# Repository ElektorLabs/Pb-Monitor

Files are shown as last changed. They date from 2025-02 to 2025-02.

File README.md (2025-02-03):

# Pb-Monitor

Pb-Monitor is a project developed by ElektorLabs aimed at monitoring lead-acid batteries. This repository contains both hardware schematics and firmware source code to facilitate the monitoring process.

## Features

- **Hardware Design**: Detailed schematics and design files for building the Pb-Monitor hardware.
- **Firmware**: Source code for the microcontroller to interface with the hardware and perform monitoring tasks.

## Repository Structure

- **hardware/**: Contains all hardware design files and schematics.
- **src/PbMonitor/**: Contains the firmware source code for the Pb-Monitor.

## Getting Started

To get started with Pb-Monitor:

1. **Clone the Repository**:
   ```bash
   git clone https://github.com/ElektorLabs/Pb-Monitor.git
   ```
2. **Explore the Hardware Design**:
   - Navigate to the `hardware/` directory to find schematics and design files.
3. **Build the Firmware**:
   - Navigate to the `src/PbMonitor/` directory.
   - Follow the build instructions provided in the source code to compile and upload the firmware to your microcontroller.

## License

This project is licensed under the GNU General Public License v3.0. For more details, refer to the [LICENSE](https://github.com/ElektorLabs/Pb-Monitor/blob/main/LICENSE) file.

## Contributing

Contributions are welcome! If you have suggestions or improvements, feel free to open an issue or submit a pull request.

## Contact

For more information or support, please contact ElektorLabs through their [GitHub profile](https://github.com/ElektorLabs).

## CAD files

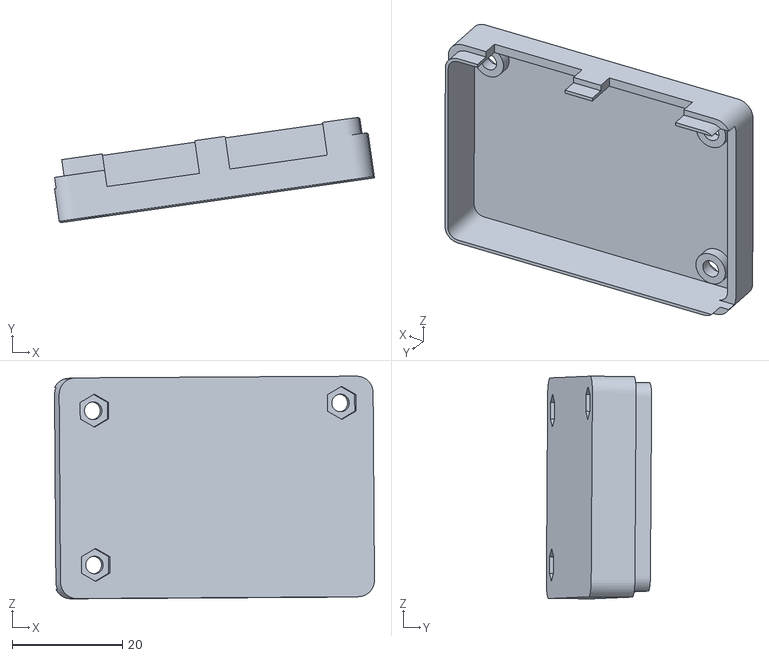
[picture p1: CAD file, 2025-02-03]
hardware/cad/stl/Pb_Enclosure - Pb Enclosure_Button-1.STL
58.0 x 19.1 x 40.4

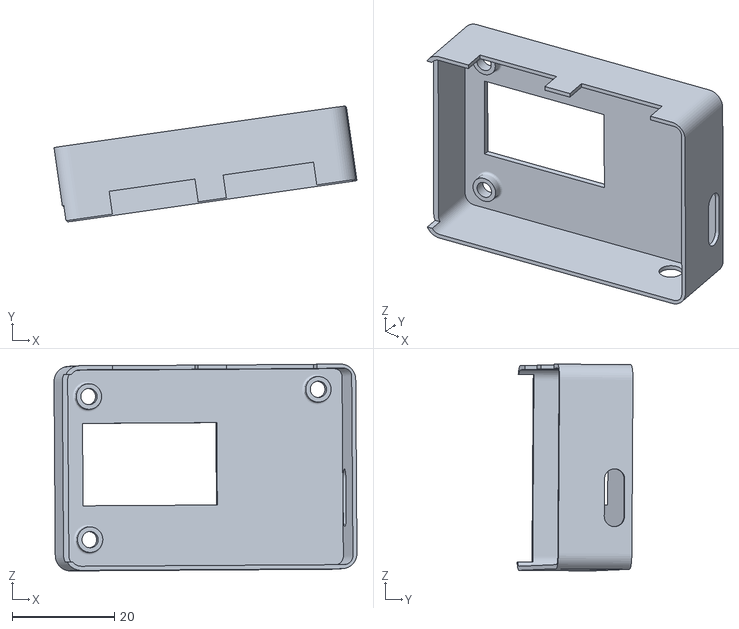
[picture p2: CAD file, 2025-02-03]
hardware/cad/stl/Pb_Enclosure - Pb Enclosure_Top-1.STL
59.2 x 22.7 x 40.4

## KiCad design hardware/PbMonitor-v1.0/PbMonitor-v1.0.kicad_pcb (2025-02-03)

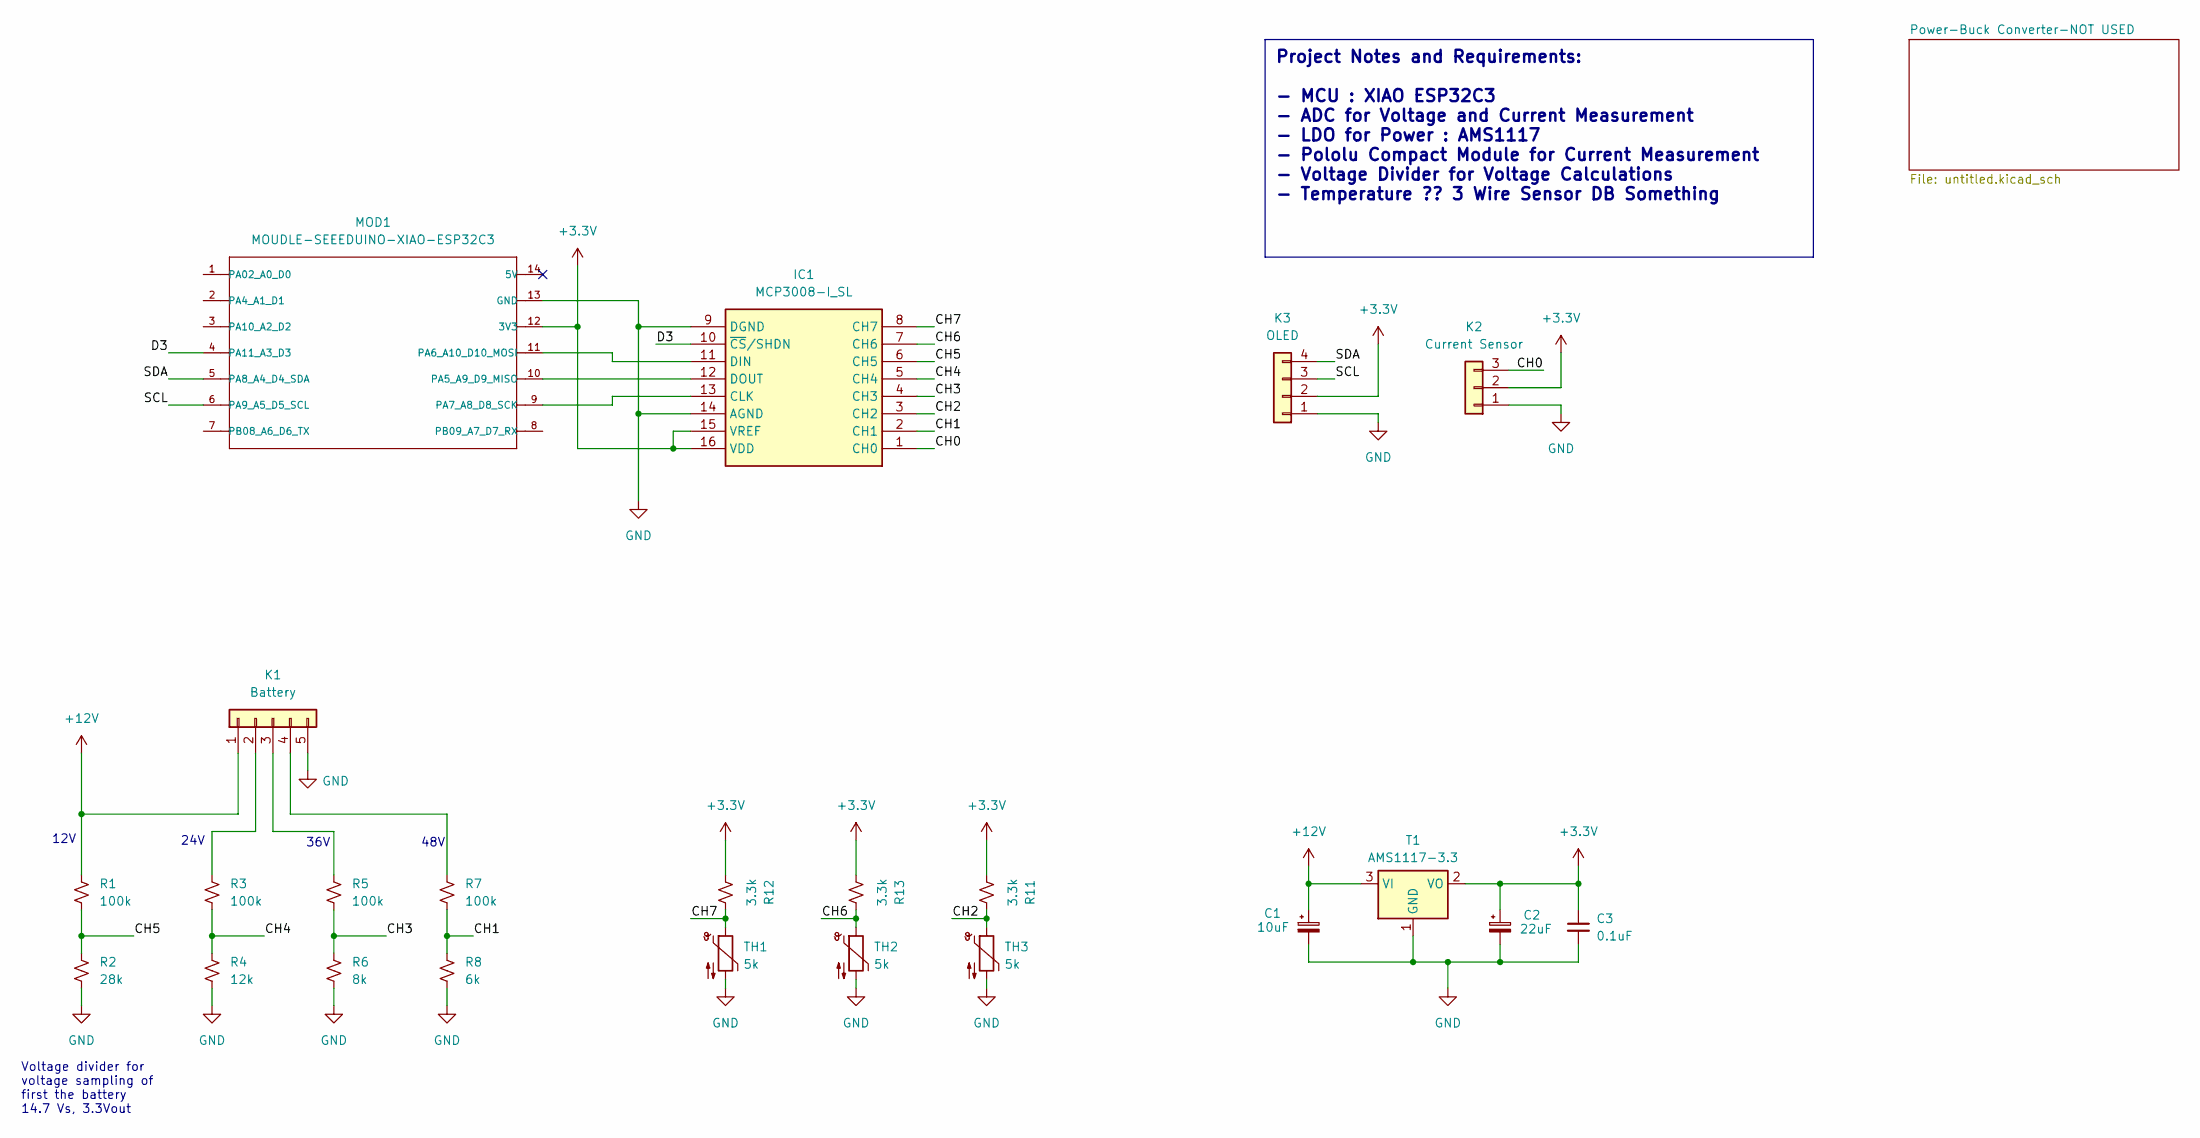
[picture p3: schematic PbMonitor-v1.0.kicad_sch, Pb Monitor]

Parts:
C1: 10uF; CP_Radial_D4.0mm_P1.50mm
C2: 22uF; CP_Radial_D4.0mm_P1.50mm
C3: 0.1uF; C_0805_2012Metric_Pad1.18x1.45mm_HandSolder
IC1: MCP3008-I_SL; SOIC127P600X175-16N; Manufacturer_Part_Number MCP3008-I/SL
K1: Battery; TerminalBlock_Xinya_XY308-2.54-5P_1x05_P2.54mm_Horizontal
K2: Current Sensor; PinHeader_1x03_P2.54mm_Vertical
K3: OLED; PinHeader_1x04_P2.54mm_Vertical
MOD1: MOUDLE-SEEEDUINO-XIAO-ESP32C3; XIAO-ESP32C3-DIP
R1, R3, R5, R7: 100k; R_Axial_DIN0204_L3.6mm_D1.6mm_P2.54mm_Vertical
R2: 28k; R_Axial_DIN0204_L3.6mm_D1.6mm_P2.54mm_Vertical
R4: 12k; R_Axial_DIN0204_L3.6mm_D1.6mm_P2.54mm_Vertical
R6: 8k; R_Axial_DIN0204_L3.6mm_D1.6mm_P2.54mm_Vertical
R8: 6k; R_Axial_DIN0204_L3.6mm_D1.6mm_P2.54mm_Vertical
R11, R12, R13: 3.3k; R_Axial_DIN0204_L3.6mm_D1.6mm_P2.54mm_Vertical
T1: AMS1117-3.3; SOT-223-3_TabPin2
TH1, TH2: 5k; JST_XH_B2B-XH-A_1x02_P2.50mm_Vertical
TH3: 5k; R_Axial_DIN0204_L3.6mm_D1.6mm_P2.54mm_Vertical

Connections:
+3.3V: C2.1, C3.1, IC1.15 (VREF), IC1.16 (VDD), K2.2, K3.2, MOD1.12 (3V3), R11.1, R12.1, R13.1, T1.2 (VO)
+12V: C1.1, K1.1, R1.1, T1.3 (VI)
/CH0: IC1.1 (CH0), K2.3
/CH1: IC1.2 (CH1), R7.2, R8.1
/CH2: IC1.3 (CH2), R11.2, TH3.1
/CH3: IC1.4 (CH3), R5.2, R6.1
/CH4: IC1.5 (CH4), R3.2, R4.1
/CH5: IC1.6 (CH5), R1.2, R2.1
/CH6: IC1.7 (CH6), R13.2, TH2.1
/CH7: IC1.8 (CH7), R12.2, TH1.1
/D3: IC1.10 (~CS/SHDN), MOD1.4 (PA11_A3_D3)
/SCL: K3.3, MOD1.6 (PA9_A5_D5_SCL)
/SDA: K3.4, MOD1.5 (PA8_A4_D4_SDA)
GND: C1.2, C2.2, C3.2, IC1.9 (DGND), IC1.14 (AGND), K1.5, K2.1, K3.1, MOD1.13 (GND), R2.2, R4.2, R6.2, R8.2, T1.1 (GND), TH1.2, TH2.2, TH3.2
unnamed: IC1.13 (CLK), MOD1.9 (PA7_A8_D8_SCK)
unnamed: IC1.11 (DIN), MOD1.11 (PA6_A10_D10_MOSI)
unnamed: IC1.12 (DOUT), MOD1.10 (PA5_A9_D9_MISO)
unnamed: K1.2, R3.1
unnamed: K1.3, R5.1
unnamed: K1.4, R7.1

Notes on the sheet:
Project Notes and Requirements: - MCU : XIAO ESP32C3 - ADC for Voltage and Current Measurement - LDO for Power : AMS1117 - Pololu Compact Module for Current Measurement - Voltage Divider for Voltage Calculations - Temperature ?? 3 Wire Sensor DB Something
36V
48V
Voltage divider for voltage sampling of first the battery 14.7 Vs, 3.3Vout
24V
12V

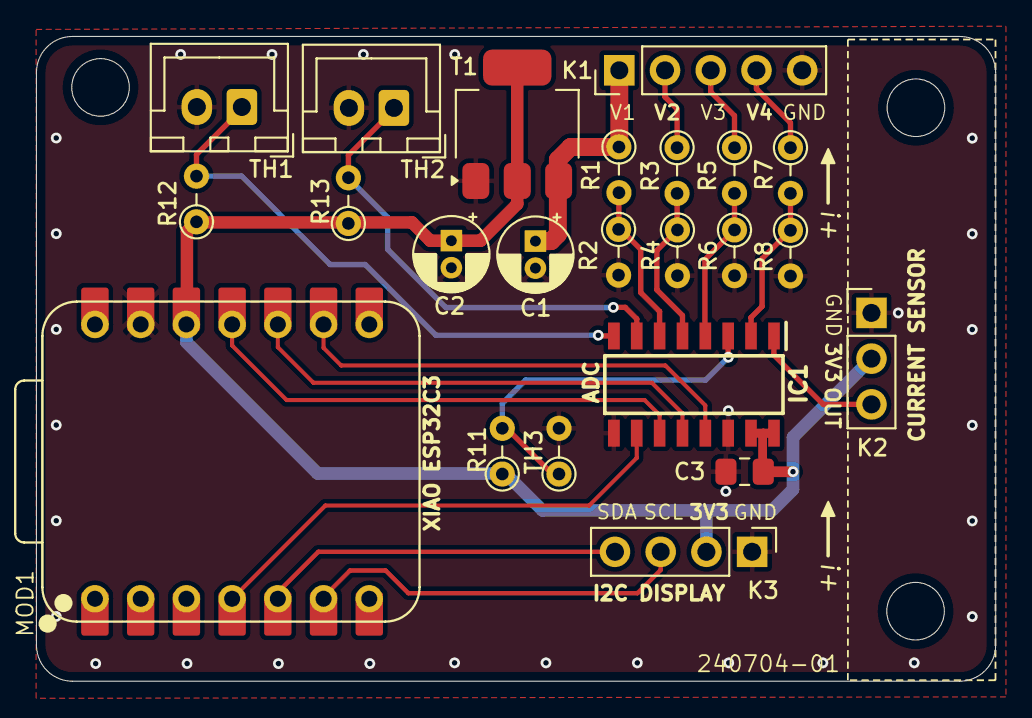
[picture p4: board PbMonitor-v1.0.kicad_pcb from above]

Board: 2 copper layers, 53.3 x 35.8 mm, 23 parts (0 on the bottom side), 20 nets.

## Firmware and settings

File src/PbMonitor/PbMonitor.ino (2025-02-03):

#include <WiFi.h>
#include <SPI.h>
#include <Adafruit_MCP3008.h>
#include <MQTTPubSubClient.h>
#include <Adafruit_GFX.h>
#include <Adafruit_SSD1306.h>
#include <config.h>
#include <esp_task_wdt.h>  // Required for watchdog timer functions

#include <ESPmDNS.h>
#include <NetworkUdp.h>
#include <ArduinoOTA.h>


// WiFi Credentials
const char* ssid = WIFISSID;      // Your WiFi SSID
const char* pass = WIFIPASSWORD;  // Your WiFi Password

WiFiClient client;
MQTTPubSubClient mqtt;

Adafruit_MCP3008 adc;
Adafruit_SSD1306 display(SCREEN_WIDTH, SCREEN_HEIGHT, &Wire, OLED_RESET);

// Global Variables for Energy Calculation
unsigned long previousMillis = 0;  // Stores the last time the energy was updated
float energyConsumed = 0;          // Total energy consumed over time in Watt-hours (Wh)
unsigned long startTime;



void setup() {

/* Initialize the serial port for debugging if DEBUG is set to true */
#if DEBUG == true
  Serial.begin(115200);
  Serial.println("*** Pb Monitor ***");  // Debugging message to indicate the start of ATM90E32 initialization
#endif



  vTaskDelay(10 / portTICK_PERIOD_MS);  // Yields CPU for 10ms

  Wire.setPins(I2C_SDA, I2C_SCL);
  Wire.begin(I2C_SDA, I2C_SCL);

  // Software SPI (specify all, use any available digital)
  // (sck, mosi, miso, cs);
  adc.begin(D8, D10, D9, D3);

  // SSD1306_SWITCHCAPVCC = generate display voltage from 3.3V internally
  if (!display.begin(SSD1306_SWITCHCAPVCC, SCREEN_ADDRESS)) {
    Serial.println(F("SSD1306 allocation failed"));
    //for(;;); // Don't proceed, loop forever
  }

  display.display();
  display.clearDisplay();

    WiFi.begin(ssid, pass);
  /* Initialize the MQTT client */
  mqtt.begin(client);
  vTaskDelay(10 / portTICK_PERIOD_MS);  // Yields CPU for 10ms
  /* Connect to WiFi, MQTT broker, and Home Assistant */
  
  connect();

  ArduinoOTA.setHostname("Pb-Monitor");



  /* Set up a subscription to handle incoming MQTT messages */
  mqtt.subscribe([](const String& topic, const String& payload, const size_t size) {
#if DEBUG == true
    Serial.println("mqtt received: " + topic + " - " + payload);  // Debugging message to show received MQTT messages
#endif
  });

  /* Subscribe to the /hello topic and set up a callback for incoming messages */
  mqtt.subscribe("/hello", [](const String& payload, const size_t size) {
#if DEBUG == true
    Serial.print("/hello ");
    Serial.println(payload);  // Debugging message to show the payload of the /hello topic
#endif
  });



  ArduinoOTA
    .onStart([]() {
      String type;
      if (ArduinoOTA.getCommand() == U_FLASH) {
        type = "sketch";
      } else {  // U_SPIFFS
        type = "filesystem";
      }

      // NOTE: if updating SPIFFS this would be the place to unmount SPIFFS using SPIFFS.end()
      Serial.println("Start updating " + type);
    })
    .onEnd([]() {
      Serial.println("\nEnd");
    })
    .onProgress([](unsigned int progress, unsigned int total) {
      Serial.printf("Progress: %u%%\r", (progress / (total / 100)));
    })
    .onError([](ota_error_t error) {
      Serial.printf("Error[%u]: ", error);
      if (error == OTA_AUTH_ERROR) {
        Serial.println("Auth Failed");
      } else if (error == OTA_BEGIN_ERROR) {
        Serial.println("Begin Failed");
      } else if (error == OTA_CONNECT_ERROR) {
        Serial.println("Connect Failed");
      } else if (error == OTA_RECEIVE_ERROR) {
        Serial.println("Receive Failed");
      } else if (error == OTA_END_ERROR) {
        Serial.println("End Failed");
      }
    });

  ArduinoOTA.begin();

  Serial.println("Ready");
  Serial.print("IP address: ");
  Serial.println(WiFi.localIP());
}

void loop() {

  ArduinoOTA.handle();
  //Periodic energy update (example: every 1 second)
  unsigned long currentMillis = millis();
  if (currentMillis - previousMillis >= 1000) {
    previousMillis = currentMillis;
    float current = readCurrent();       // Read current in Amps
    float voltage = batteryVoltages(5);  // Read voltage in Volts
    float power = voltage * current;     // Calculate power in Watts
    energyConsumed += power / 3600;      // Convert power to Wh and accumulate
  }
  vTaskDelay(10 / portTICK_PERIOD_MS);  // Yields CPU for 10ms
  updateDisplay();
  vTaskDelay(10 / portTICK_PERIOD_MS);  // Yields CPU for 10ms
  // /* Keep the MQTT client updated */
  mqtt.update();
  vTaskDelay(10 / portTICK_PERIOD_MS);  // Yields CPU for 10ms
  // /* Reconnect to the MQTT broker if the connection is lost */
  if (!mqtt.isConnected()) {
    connect();
  }

  /* Check and send energy data to Home Assistant every 3 seconds */
  static uint32_t prev_ms = millis();
  if (millis() > prev_ms + 3000) {
    prev_ms = millis();
    sendData();  // Retrieve energy data and send via MQTT
  }
}

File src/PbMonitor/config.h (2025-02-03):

#define DEBUG true  // Make this false if Serial Monitor is not required.

#define WIFISSID "xxxx"
#define WIFIPASSWORD "xxxx"

#define HOMEASSISTANT_IP "xxx"
#define DEVICE_NAME "Pb-Monitor"
#define USER_ID "xxx"
#define PASSWORD "xxx"


#define I2C_SDA D4
#define I2C_SCL D5

#define ZERO_ERROR_V 0
#define ZERO_ERROR_C 0.20

// Voltage Dividers
#define R1 97.8
#define R2 21.81
#define R3 98.1
#define R4 9.86
#define R5 106
#define R6 6.69
#define R7 98.5
#define R8 4.595

#define R12 98000
#define R13 9800


// ADC and Voltage Reference Constants
const float V_REF = 3.29; // ADC reference voltage
const int ADC_MAX = 1023; // 10-bit ADC resolution

// Steinhart-Hart Coefficients for 10K Thermistor (Adjust as per your thermistor datasheet)
const float A_10K = 0.001129148;
const float B_10K = 0.000234125;
const float C_10K = 0.0000000876741;

// Steinhart-Hart Coefficients for 100K Thermistor (Adjust as per your thermistor datasheet)
const float A_100K = 0.000827257;
const float B_100K = 0.000215191;
const float C_100K = 0.00000009304;




// Assuming a fixed battery capacity for SoC estimation (e.g., 100Wh for demonstration)
#define batteryCapacityWh  1920 // Replace with actual battery capacity

#define SCREEN_WIDTH 128 // OLED display width, in pixels
#define SCREEN_HEIGHT 64 // OLED display height, in pixels

#define OLED_RESET     -1 // Reset pin # (or -1 if sharing Arduino reset pin)
#define SCREEN_ADDRESS 0x3C ///< See datasheet for Address; 0x3D for 128x64, 0x3C
